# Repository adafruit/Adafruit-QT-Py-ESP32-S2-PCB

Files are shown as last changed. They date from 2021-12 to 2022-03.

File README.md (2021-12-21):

## Adafruit QT Py ESP32-S2 WiFi Dev Board with STEMMA QT PCB

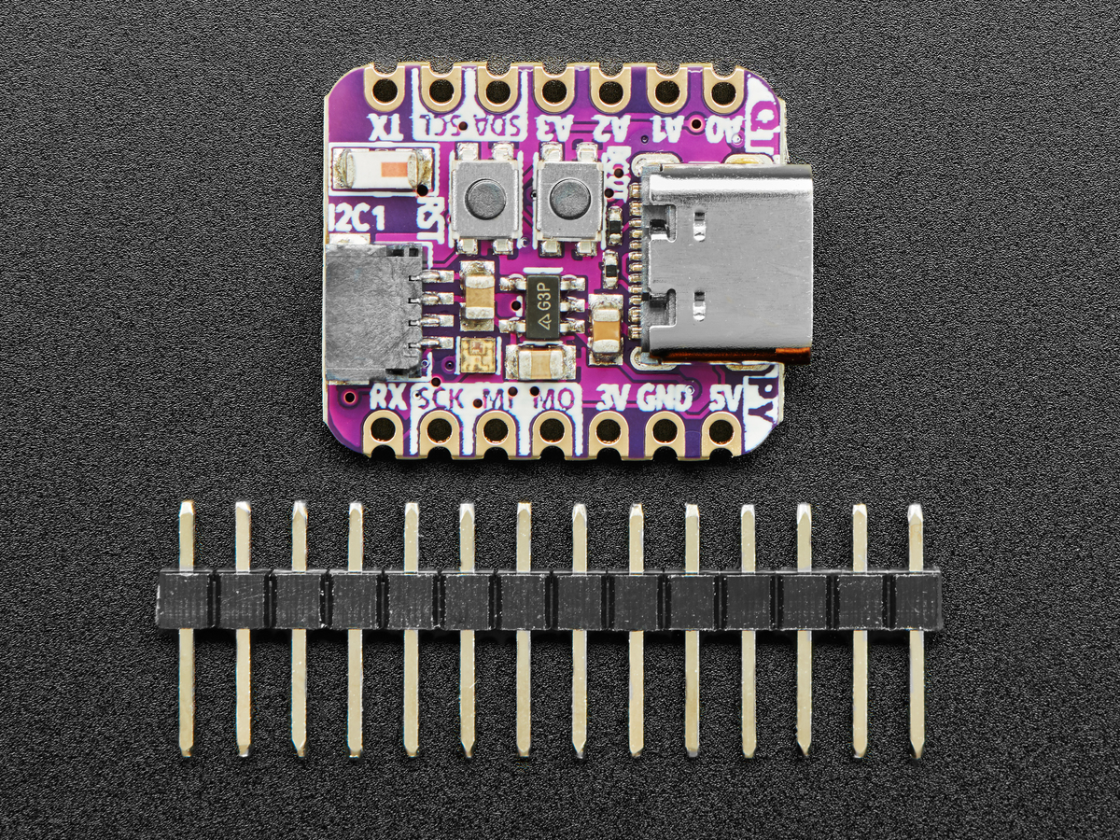
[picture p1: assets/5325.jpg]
<a href="http://www.adafruit.com/products/5325"><br/>
Click here to purchase one from the Adafruit shop</a>

PCB files for the Adafruit QT Py ESP32-S2 WiFi Dev Board with STEMMA QT. 

Format is EagleCAD schematic and board layout
* https://www.adafruit.com/product/5325

### Description

What has your favorite Espressif WiFi microcontroller, comes with our favorite connector - the STEMMA QT, a chainable I2C port, and has lots of Flash and RAM memory for your next IoT project? What will make your next IoT project flyyyyy? What a cutie pie! Or is it... a QT Py? This diminutive dev board comes with one of our new favorite lil chips, the ESP32-S2! 

The ESP32-S2 is a highly-integrated, low-power, 2.4 GHz Wi-Fi System-on-Chip (SoC) solution that now has built-in native USB as well as some other interesting new technologies like Time of Flight distance measurements. With its state-of-the-art power and RF performance, this SoC is an ideal choice for a wide variety of application scenarios relating to the Internet of Things (IoT), wearable electronics, and smart homes.

Please note the QT Py ESP32-S2 has a single-core 240 MHz chip, so it won't be as fast as ESP32's with dual-core. Also, there is no Bluetooth support. However, we are super excited about the ESP32-S2's native USB which unlocks a lot of capabilities for advanced interfacing! This ESP32-S2 mini-module we are using on the QT Py comes with 4 MB flash and 2 MB PSRAM so you can buffer massive JSON files for parsing!

OLEDs! Inertial Measurement Units! Sensors a-plenty. All plug-and-play thanks to the innovative chainable design: SparkFun Qwiic-compatible STEMMA QT connectors for the I2C bus so you don't even need to solder! Just plug in a compatible cable and attach it to your MCU of choice, and you’re ready to load up some software and measure some light. Seeed Grove I2C boards will also work with this adapter cable.

Pinout and shape are Seeed Xiao compatible, with castellated pads so you can solder it flat to a PCB. In addition to the QT connector, we also added an RGB NeoPixel (with controllable power pin to allow for ultra-low-power usage), a reset button (great for restarting your program or entering the bootloader) and a button on GPIO 0 for entering the ROM bootloader or for user input

Runs Arduino like a dream, and CircuitPython projects are fantastically fun.

### License

Adafruit invests time and resources providing this open source design, please support Adafruit and open-source hardware by purchasing products from [Adafruit](https://www.adafruit.com)!

Designed by Limor Fried/Ladyada for Adafruit Industries.

Creative Commons Attribution/Share-Alike, all text above must be included in any redistribution. 
See license.txt for additional details.

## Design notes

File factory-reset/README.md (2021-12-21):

## Factory Reset file - QT Py ESP32-S2 WiFi Dev Board with STEMMA QT

This is the factory reset file for the QT Py ESP32-S2 WiFi Dev Board with STEMMA QT.

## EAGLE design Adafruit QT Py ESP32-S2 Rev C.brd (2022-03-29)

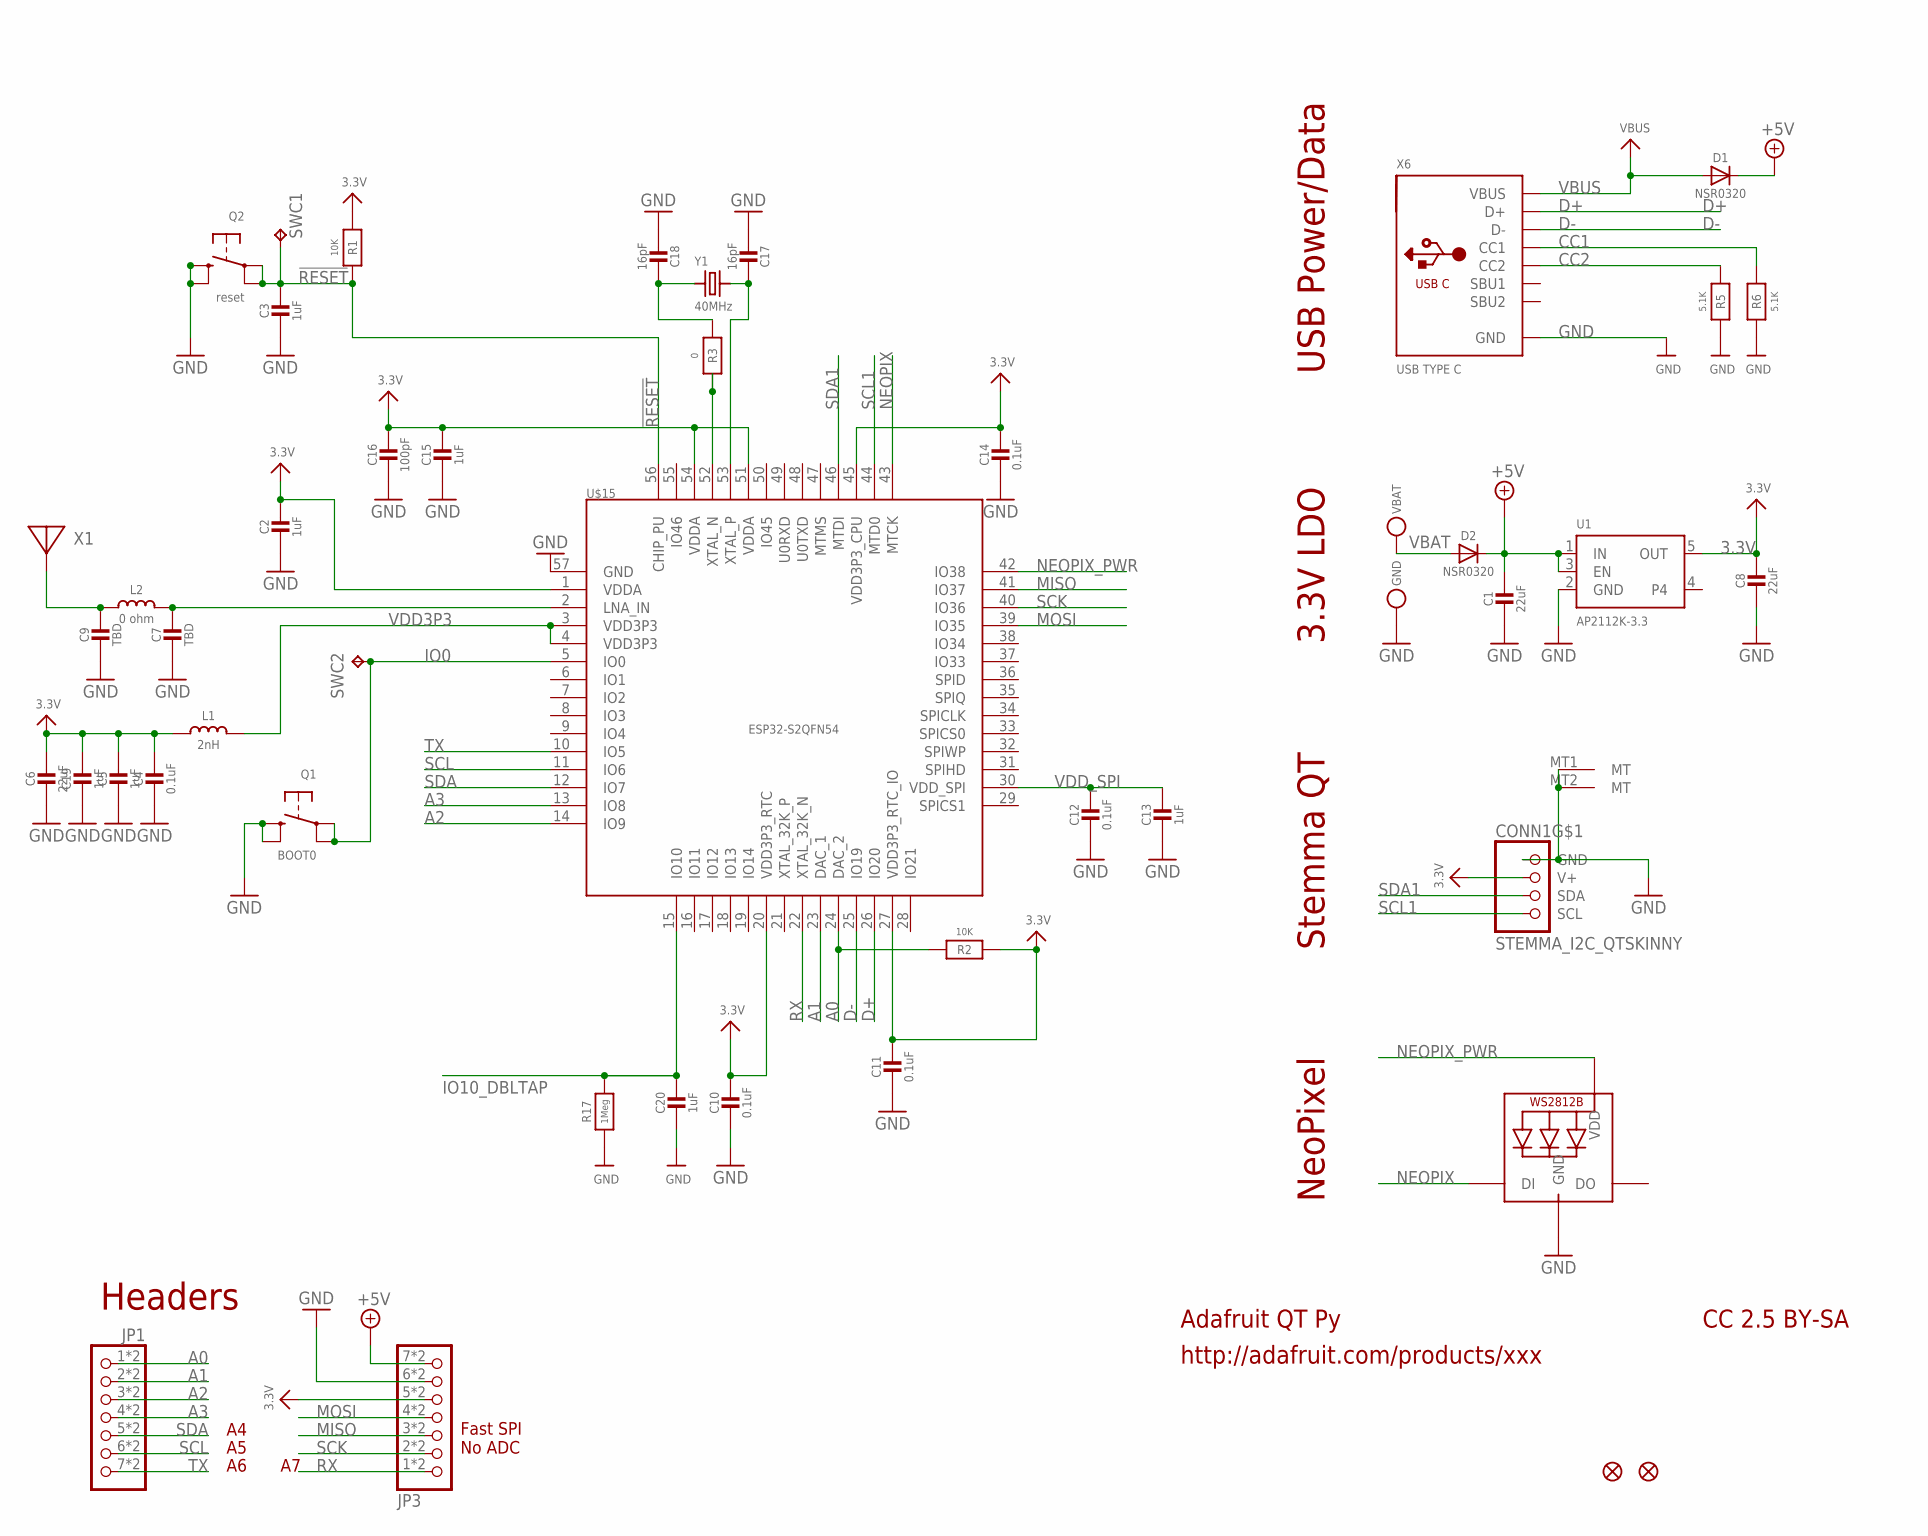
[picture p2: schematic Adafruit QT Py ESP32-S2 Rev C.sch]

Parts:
C1, C6, C8: 22uF; 0805-NO
C2, C3, C5, C13, C15, C19, C20: 1uF; _0402NO
C4, C10, C11, C12, C14: 0.1uF; _0402NO
C7, C9: TBD; _0402NO
C16: 100pF; _0402NO
C17, C18: 16pF; _0402NO
CONN1: STEMMA_I2C_QTSKINNY; JST_SH4_SKINNY
D1, D2: NSR0320; SOD-323_MINI
GND: TESTPOINT_MINUS; TESTPOINT_MINUS_1X3MM
JP1, JP3: HEADER-1X7_CASTEL; 1X07_CASTEL
L1: 2nH; _0402
L2: 0 ohm; _0402
LED1: WS2812B_SK6805_1515; SK6805_1515
Q1: BOOT0; BTN_KMR2_4.6X2.8
Q2: reset; BTN_KMR2_4.6X2.8
R1, R2: 10K; _0402NO
R3: 0; _0402NO
R5, R6: 5.1K; _0402NO
R17: 1Meg; _0402NO
SWC1, SWC2: TPB1,27; B1,27
U1: AP2112K-3.3; SOT23-5
U$6, U$8: FIDUCIAL_1MM
U$15: ESP32-S2QFN54; QFN56_7X7
VBAT: TESTPOINT_PLUS13; TESTPOINT_PLUS_1X3MM
X1: ANTENNA_JOHANSON_2450AT18B100; ANT_2450AT18B100
X6: USB TYPE C; USB_C_CUSB31-CFM2AX-01-X
Y1: 40MHz; CRYSTAL_2X1.6

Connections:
3.3V: C2.1, C4.1, C5.1, C6.1, C8.1, C10.1, C11.1, C14.1, C15.1, C16.1, C19.1, CONN1.2 (V+), JP3.5, JP3.5C (5), L1.1, R1.1, R2.1, U1.5 (OUT), U$15.1 (VDDA), U$15.20 (VDD3P3_RTC), U$15.27 (VDD3P3_RTC_IO), U$15.45 (VDD3P3_CPU), U$15.51 (VDDA), U$15.54 (VDDA)
!RESET: C3.1, Q2.A, Q2.A' (P1), R1.2, SWC1.TP, U$15.56 (CHIP_PU)
+5V: C1.1, D1.C, D2.C, JP3.7, JP3.7C (7), U1.1 (IN), U1.3 (EN)
A0: JP1.1, JP1.1C (1), R2.2, U$15.24 (DAC_2)
A1: JP1.2, JP1.2C (2), U$15.23 (DAC_1)
A2: JP1.3, JP1.3C (3), U$15.14 (IO9)
A3: JP1.4, JP1.4C (4), U$15.13 (IO8)
CC1: R6.2, X6.A5 (CC1)
CC2: R5.2, X6.B5 (CC2)
D+: U$15.26 (IO20), X6.A6 (D+), X6.B6 (D+)
D-: U$15.25 (IO19), X6.A7 (D-), X6.B7 (D-)
GND: C1.2, C2.2, C3.2, C4.2, C5.2, C6.2, C7.2, C8.2, C9.2, C10.2, C11.2, C12.2, C13.2, C14.2, C15.2, C16.2, C17.2, C18.2, C19.2, C20.2, CONN1.1 (GND), CONN1.MT1 (MT), CONN1.MT2 (MT), GND.P$1, JP3.6, JP3.6C (6), LED1.4 (GND), Q1.B (S), Q1.B' (S1), Q2.B (S), Q2.B' (S1), R5.1, R6.1, R17.1, U1.2 (GND), U$15.57 (GND), X6.A1B12 (GND), X6.B1A12 (GND)
IO0: Q1.A, Q1.A' (P1), SWC2.TP, U$15.5 (IO0)
IO10_DBLTAP: C20.1, R17.2, U$15.15 (IO10)
MISO: JP3.3, JP3.3C (3), U$15.41 (IO37)
MOSI: JP3.4, JP3.4C (4), U$15.39 (IO35)
unnamed: C7.1, L2.2, U$15.2 (LNA_IN)
unnamed: C9.1, L2.1, X1.FP
unnamed: R3.2, U$15.52 (XTAL_N)
unnamed: C17.1, U$15.53 (XTAL_P), Y1.3 (2)
unnamed: C18.1, R3.1, Y1.1
NEOPIX: LED1.1 (DI), U$15.43 (MTCK)
NEOPIX_PWR: LED1.2 (VDD), U$15.42 (IO38)
RX: JP3.1, JP3.1C (1), U$15.22 (XTAL_32K_N)
SCK: JP3.2, JP3.2C (2), U$15.40 (IO36)
SCL: JP1.6, JP1.6C (6), U$15.11 (IO6)
SCL1: CONN1.4 (SCL), U$15.44 (MTD0)
SDA: JP1.5, JP1.5C (5), U$15.12 (IO7)
SDA1: CONN1.3 (SDA), U$15.46 (MTDI)
TX: JP1.7, JP1.7C (7), U$15.10 (IO5)
VBAT: D2.A, VBAT.P$1
VBUS: D1.A, X6.A4B9 (VBUS), X6.B4A9 (VBUS)
VDD3P3: L1.2, U$15.3 (VDD3P3), U$15.4 (VDD3P3)
VDD_SPI: C12.1, C13.1, U$15.30 (VDD_SPI)

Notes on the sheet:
Adafruit QT Py
http://adafruit.com/products/xxx
CC 2.5 BY-SA
NeoPixel
Stemma QT
3.3V LDO
USB Power/Data
Headers
Fast SPI No ADC

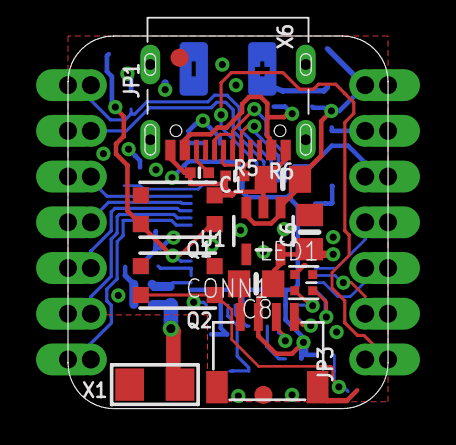
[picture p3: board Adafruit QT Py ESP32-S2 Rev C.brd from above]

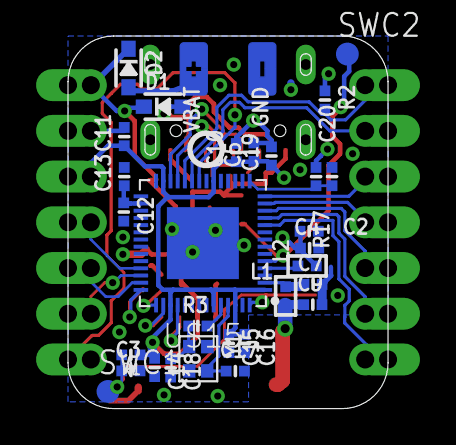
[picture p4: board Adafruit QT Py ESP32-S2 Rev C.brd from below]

Board: 4 copper layers, 17.8 x 20.7 mm, 50 parts (33 on the bottom side), 34 nets.

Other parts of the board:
U$7: QTPYS2_BOT
U$12: PCBFEAT-REV-040
U$13: QTPY_ESP32_TOP

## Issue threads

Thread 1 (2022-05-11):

QT-Py-ESP32-S2

igotab, 2022-05-11:
Your QT-Py-ESP32-S2 pinout shows TXD on GPIO5 (ESP32-S2 pin 10) and RXD on GPIO16 (ESP32-S2 pin 22).
These are not the hardware UART pins of ESP32-S2.

Can you please shed some light on this.

igotab, 2022-05-11:
Me again,
I traced the pins on your PCB fab. RXD is connected to GPIO44 (not to GPIO16) that is indeed a UART RXD pin
but TXD is connected to GPIO5 that is not a TXD pin.

ladyada, 2022-05-15:
the s2 can mux uart to any pins, we use native usb not hardware uart

Closed 2022-05-15.

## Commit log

2021-12-21 Added PCB files
    [Adafruit QT Py ESP32-S2.brd, Adafruit QT Py ESP32-S2.sch]
2022-01-13 Add uFL board files.
    [Adafruit QT Py ESP32-S2 uFL.brd, Adafruit QT Py ESP32-S2 uFL.sch]
2022-03-29 Add latest board files.
    [Adafruit QT Py ESP32-S2 Rev C.brd, Adafruit QT Py ESP32-S2 Rev C.sch]

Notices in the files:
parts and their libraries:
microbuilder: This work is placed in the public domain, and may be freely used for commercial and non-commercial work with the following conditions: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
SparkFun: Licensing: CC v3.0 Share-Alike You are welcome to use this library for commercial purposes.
